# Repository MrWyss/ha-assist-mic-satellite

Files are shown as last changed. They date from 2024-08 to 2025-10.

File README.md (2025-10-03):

# Voice Assistant Mic Satellite







<p align="center">
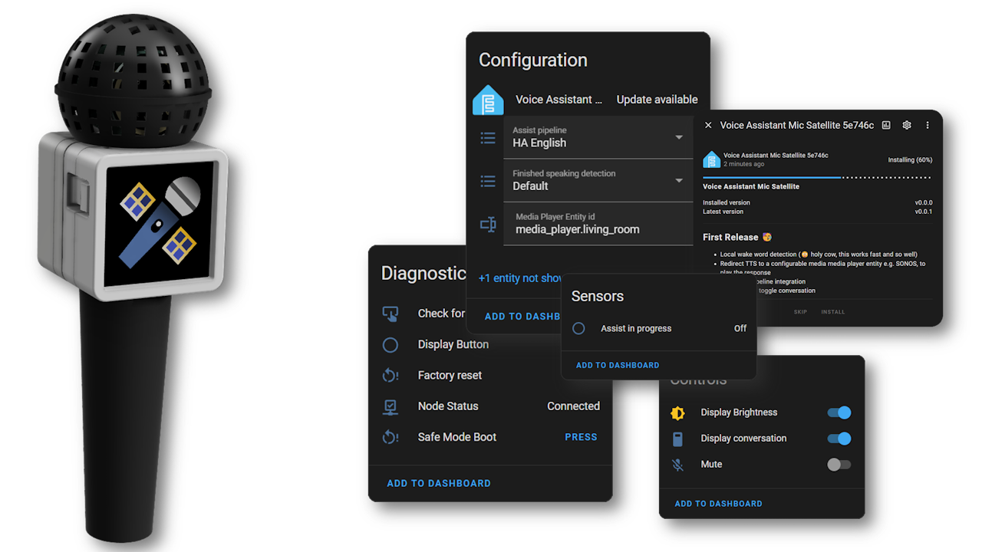
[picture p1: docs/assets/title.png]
Title Logo
  
</p>

***<p align="center" style="text-align: center;">«The VA Mic Satellite is a compact, ESPHome-based microphone solution designed to integrate with your existing sound setup..»</p>***

>📢 2025-10-03: Firmware release [v2.0.0](https://github.com/MrWyss/ha-assist-mic-satellite/releases/tag/v2.0.0) 🎉🎉🎉: **Mayor Release**, this pushes the [M5Stack AtomS3](https://docs.m5stack.com/en/core/AtomS3) to **it's limit**. With these new features 
> - Option to change from "Okey Nabu" to "Hey Jarvis" and back
> - "Set Up Voice Assistant" wizard will run on first boot
> - ESPHome 2025.9.2
>
>... [Read more](https://github.com/MrWyss/ha-assist-mic-satellite/releases)
>
>📢 2024-08-19: Version 1 released. 🎉🎉🎉 and  [PCB rev. 3](https://github.com/MrWyss/ha-assist-mic-satellite/discussions/15#discussion-7049397) has arrived and tested successfully. 🥳. See the new firmware [in action](https://github.com/MrWyss/ha-assist-mic-satellite/discussions/16#discussioncomment-10387199) on a [mic stand](https://github.com/MrWyss/ha-assist-mic-satellite/discussions/16#discussioncomment-10387101) 😆.
>
>📢 2024-08-12: I just came across the [announcement](https://www.youtube.com/watch?v=Vp5q4RIwCX4) of **Satellite1** by [Future Proof Homes](https://futureproofhomes.net). It’s an amazing initiative! 😎 My project is entirely different and not comparable to theirs. The similar name is just a coincidence. Definitely check them out!

## Features

A ~~tiny~~ Atom version of the [ESP32-S3-BOX](https://esphome.io/projects/index.html)

- Local / On Device **wake word detection** (😲 holy cow, this works fast and so well)
- Redirect TTS to a configurable **media player entity** e.g. SONOS, to play the response
- HA **Assist Pipeline integration**
- Toggle **mute**, toggle **conversation text** and control display **brightness**
- **Show current state** (listening, idle, request, response) on the display. It is fairly readable, though it requires good eyesight 👀.
- **Timers** support (plural), realistically up to 4 timers
- Easy firmware flashing via the [web installer](https://mrwyss.github.io/ha-assist-mic-satellite/)
- Managed updates

### Roadmap

If anyone is interested in contributing, here are some ideas:

- [ ] Better alarm **sound files** [#10](https://github.com/MrWyss/ha-assist-mic-satellite/issues/10)
  
## TL;DR

Gather the following items: [M5Stack AtomS3](#bom), [pcb](#pcb), [pin headers and pin sockets](#bom) and an [INMP441](#bom) breakout board.
3D print the [case](#case), [assemble](#assembly) it, [flash the firmware](#firmware), [configure](#home-assistant) the device in Home Assistant.

## Try it out / Tricks

- **Wake Word**: "Okay Nabu" (or "Hey Jarvis")
- Create a timer, *Create a 3 minute timer for Bananas*, *Cancel Bananas timer*
- The display itself is also a button, so you can **long press (~800ms) to mute** the device, it stops listening for the wake word. Holding for ~10s factory resets the device.
- If you have [Music Assistant](https://music-assistant.io) you can change the **announcement volumes**. Goto the Music Assistant Addon -> Settings -> Players -> Your Speaker -> Configure -> Announcements configuration

## Hardware

### BOM

- [M5Stack AtomS3](https://docs.m5stack.com/en/core/AtomS3) ~15$
- [PCB](#pcb) ~5$ + shipping
- [Case](#case) ~0.5$ filament
- **INMP441** breakout board (usually comes with pin sockets) ~2$
  - 2x Pin socket 1x03 2.54mm (J3, J4)
- 1x Pin header 1x05 2.54mm (J1)
- 1x Pin header 1x04 2.54mm (J2)
- M2 x 5mm screw nylon or with metal with nylon washer (optional)

### PCB

The pcb was designed in KiCAD. [KiCAD Canvas Online View](https://kicanvas.org/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) | [KiCad Project](pcb/Mic%20HAT%20for%20M5Stack%20Atom) | [PCB Step File](<pcb/Mic HAT for M5Stack Atom/Mic HAT for M5Stack Atom.step>)

Order from [PCBWay Project Link](https://www.pcbway.com/project/shareproject/HA_Assist_Mic_Satellite_f5cc4682.html) (🛒 affiliated link)

| PCB front | PCB back |
|:---:|:---:|
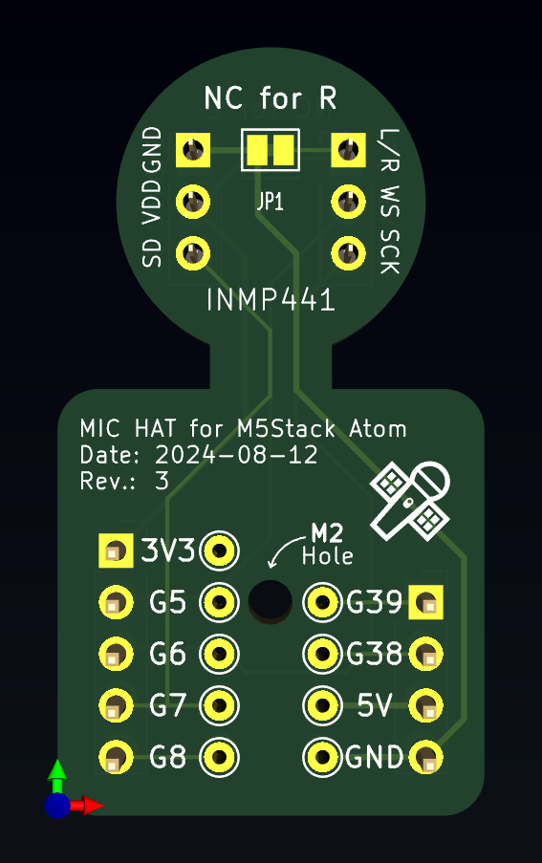
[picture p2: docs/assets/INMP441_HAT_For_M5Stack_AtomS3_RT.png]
PCB Front
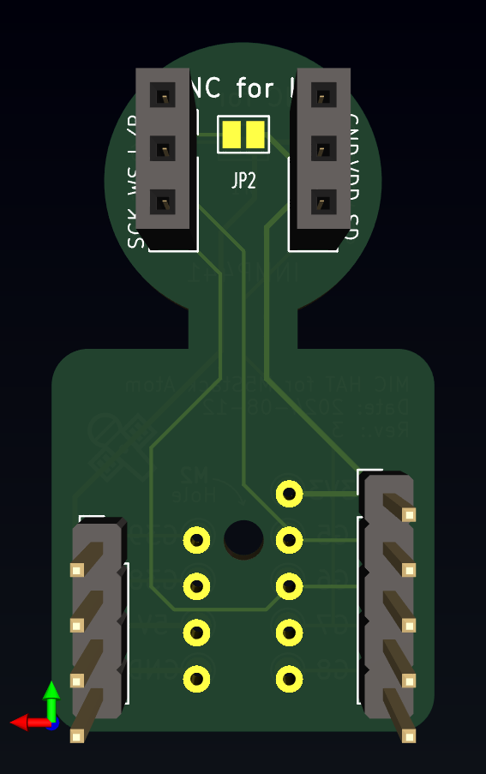
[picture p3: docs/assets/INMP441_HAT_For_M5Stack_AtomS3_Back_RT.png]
PCB Back
| | |

### Case

#### Hat

The case was designed in Fusion 360 and exported as 3mf files and step files. [Step files](case/step) | [3mf files](case/3mf)
It shouldn't need any supports for 3d printing, but I recommend printing it with your high detail settings. It is rather small.

- [Hat case body](case/3mf/MicHatCaseBody.3mf)
- [Hat case top](case/3mf/MicHatCaseTop.3mf)

#### Optional (boom, wind screen, stand)

[Boom for Grove connector](case/3mf/MicHatHolderGrove.3mf), the boom was designed for the Grove connector, as it is more centered. I sacrificed a sleeved USB cable and attached a Grove connector to it. It's supposed to be a press fit. [Mic wind screen](case/3mf/MicHatCaseWindShield.3mf), this is purely cosmetic and serves no functional purpose. [Mic stand](case/3mf/MicStandMicAll.3mf), to assemble the mic stand, you need a 8mm (~1 meter / hollow) aluminum rod. Cut into approximately three 10cm pieces, one 20cm (vertical) and one 25cm (horizontal).

### Assembly

Pretty straight forward. Solder the header sockets and pins to the pcb and to the INMP441.

>❗Check the direction of the header sockets and pins. Especially on the INMP441, the side with mic icon should face the same direction as the screen.

Put it in the case, screw it together and attach the HAT to the AtomS3.

<p align="center">
  
</p>

## Software

- [Home Assistant](https://www.home-assistant.io) (*ESPHome not required only if you want to adopt the device*)
- [Music Assistant](https://music-assistant.io) (optional)
- A **media player entity** (e.g. media_player.office)

### Firmware

The firmware is available here: [Web Installer](https://mrwyss.github.io/ha-assist-mic-satellite/) or [ESPHome yaml](code/esphome/va-mic-sat-atoms3.yaml)

This has been frankensteined together from various sources. I will try to give [credit](#credits) where [credit](#credits) is due.

### Home Assistant

The device should get auto discovered.

We need to tick **Allow the device to perform Home Assistant actions**. Since the firmware will call the `media_player.play_media` service, we need to allow this.
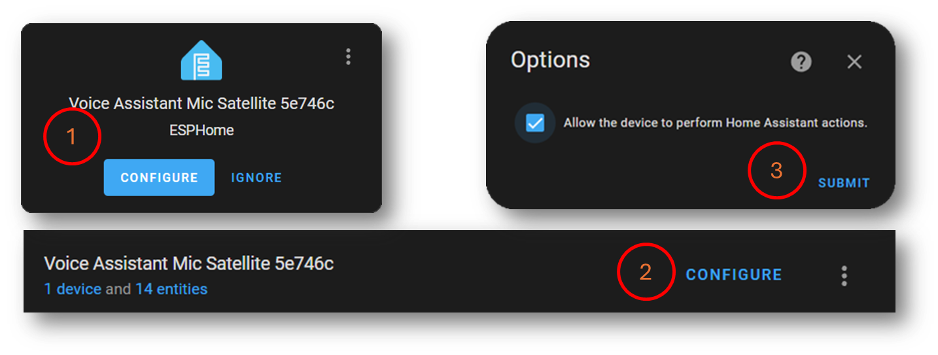
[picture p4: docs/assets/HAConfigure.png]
Configure ESPHome Device


While you here, click on **device** and change paste your media player entity id where the announcement should be played.

### Sounds

There are **two** sound files required. One for when the device is listening, this is the silent wav file, the second is for the alarm ringtone.

Currently the firmware is configured that the media player streams the files directly from github, in other words it (media_player) requires an internet connection. If you want to change this, adopt the device in ESPHome and change the following lines to something like this:

```yaml
substitutions:
  # ....
  timer_sound_file: media-source://media_source/local/my-alarm.mp3
  silence_sound_file: media-source://media_source/local/my-silence.mp3
```

To copy the sound files to for instance the home assistant, you can use the vscode addon or samba share. See more [Home Assistant Docs](https://www.home-assistant.io/integrations/media_source/)

## How it works

### Simplified Process

```mermaid
sequenceDiagram
    participant Mic Satellite
    participant Assist Pipeline
    participant media_player
    Mic Satellite->Mic Satellite: wake word detection
    Mic Satellite->>media_player: trigger action media_player.play_media (announcement / silent audio)
    media_player->media_player: lower volume
    Mic Satellite->Mic Satellite: listening  
    Mic Satellite->>Assist Pipeline: send intent audio
    Assist Pipeline->>Mic Satellite: response mp3_url
    Mic Satellite->>media_player: trigger action media_player.play_media (announcement / mp3_url)
    media_player->media_player: play response
```

### Wiring / Schematics

[KiCAD Schematic](<pcb/Mic HAT for M5Stack Atom/Mic HAT for M5Stack Atom.kicad_sch>) | [KiCAD Canvas Online View](https://kicanvas.org/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)

All the the pcb hat does is connecting the INMP441 pins to the AtomS3 pins.

<details><summary>Pin mapping table</summary>

|AtomS3 Pin|INMP441 Pin|
|:---:|:---:|
|3V3| VDD|
|GND | GND + L/R|
|G5 (GPIO5) | WS|
|G6 (GPIO6) | SCK|
|G7 (GPIO7) | SD|

</details>

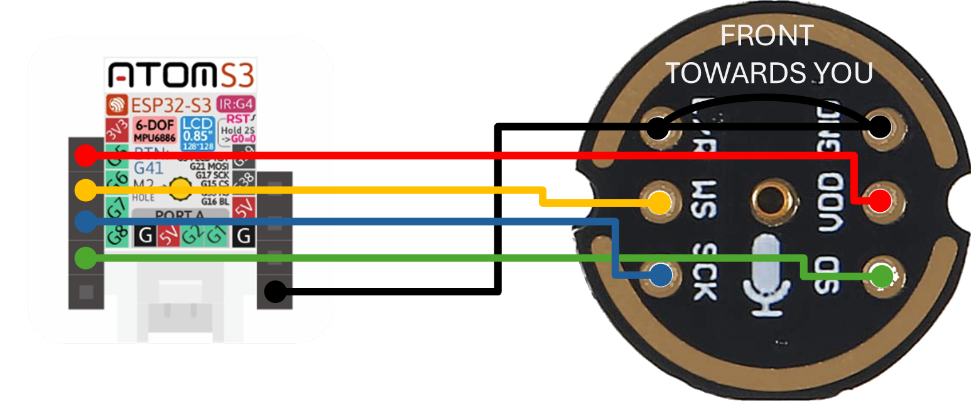
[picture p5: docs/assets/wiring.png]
wiring


Additionally, it exposes the remaining pins of the AtomS3 and adds two solder bridges (JP1 and JP2). G8, G38, and G39 are available to use for other purposes. So is the Grove connector (G1, G2). Power (+3V3 and +5V) and ground are also available.

The solder bridges are used to change the audio channel, left or right. There are two configurations:

- Left channel: JP1 bridged and JP2 not bridged (default)
- Right channel: JP1 not bridged and JP2 bridged

>❗To change the configuration, both solder bridges need to be modified. Cut one and bridge the other. I cloud otherwise short +3V3 to GND.

## Picture Gallery

<details><summary>Videos and Pictures</summary>

### Demo Video v1.0.0

https://github.com/user-attachments/assets/9a9f7f58-b787-4129-acef-4c1b4aa1fa7d

### Demo Pictures v1.0.0

Mic Stand

### Close Ups

|Close up | Full device with cable&nbsp;&nbsp;&nbsp;&nbsp;&nbsp;&nbsp;&nbsp;&nbsp;&nbsp;&nbsp;&nbsp;&nbsp;&nbsp;&nbsp;&nbsp;&nbsp;&nbsp;&nbsp;&nbsp;&nbsp;&nbsp;&nbsp;&nbsp;&nbsp;&nbsp;&nbsp;&nbsp;&nbsp;&nbsp;&nbsp;&nbsp;&nbsp;&nbsp;&nbsp;&nbsp;&nbsp;&nbsp;&nbsp;&nbsp;&nbsp;&nbsp;&nbsp;&nbsp;&nbsp;&nbsp;&nbsp;&nbsp;&nbsp;&nbsp;&nbsp;&nbsp;&nbsp;&nbsp;&nbsp;&nbsp;&nbsp;|
|:---:|:---:|
|Close Up | Full device with cable|

### Archive

|Muted |  Intent in Action|
|:---:|:---:|
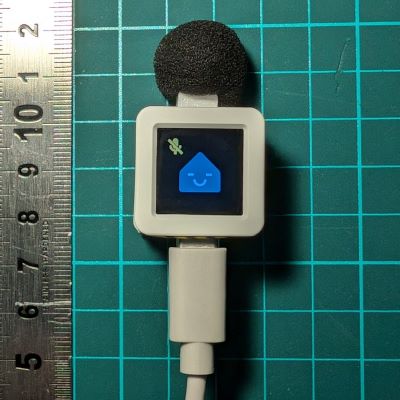
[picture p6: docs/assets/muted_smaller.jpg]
Muted
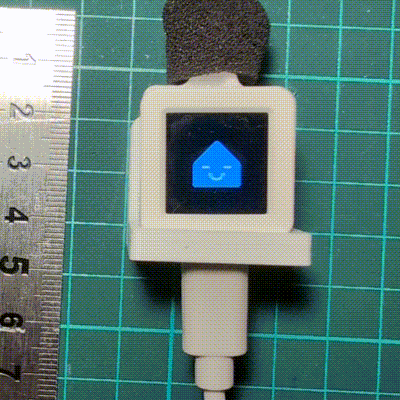
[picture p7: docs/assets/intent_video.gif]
Intent in Action
| | |

</details>

## Background

I am not an electrical engineer nor a software developer. This project is for fun and to learn new things, such as PCB design with KiCad, CAD, and ready-made ESPHome projects.

I am aware that Nabu Casa is working on a [Voice Kit](https://github.com/esphome/voice-kit); in fact, many things are directly taken from their project.
I am excited to see what the final product will look like and might even buy it myself.

My motivation was to have a small device that integrates with my existing sound setup (SONOS, in my case) rather than having a separate speaker.

## License

I wasn't sure if I should use the same license as the ESPHome project, but I think it is fine.

## Contributing

**Please do**, create issues, pull requests, open a discussion or DM me here. I am happy to help and learn from you.

## Credits

- [HA Voice Kit](https://github.com/esphome/voice-kit)
- [ESPHome Voice Assistant Github Repo](https://github.com/esphome/firmware/tree/main/voice-assistant/)
- [Smart Home Circle](https://smarthomecircle.com/How-I-created-my-voice-assistant-with-on-device-wake-word-using-home-assistant)
- [Community](https://community.home-assistant.io/t/esphome-voice-assistant-speech-output-to-home-assistant-media-player/588337/18)
- And obviously the Nabu Casa team

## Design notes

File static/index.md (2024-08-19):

# About

The Voice Assistant Mic Satellite is a compact, ESPHome-based microphone solution designed for seamless integration with Home Assistant.

# Installation

You can use the button below to install the pre-built firmware directly to your device via USB from the browser.

<esp-web-install-button manifest="./firmware/manifest.json"></esp-web-install-button>

<script type="module" src="https://unpkg.com/esp-web-tools@9/dist/web/install-button.js?module"></script>

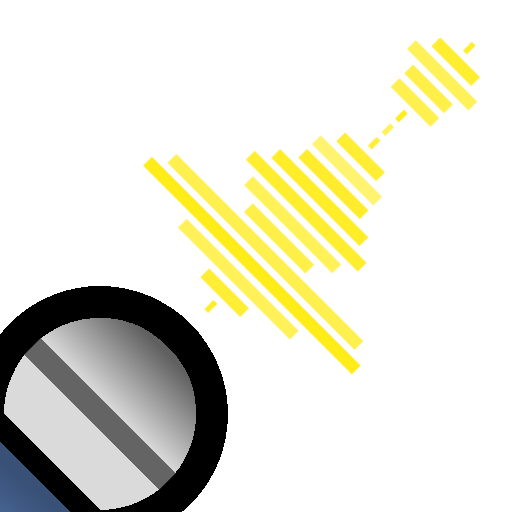
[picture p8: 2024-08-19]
code/esphome/media/animation/micsatellite_listening.png

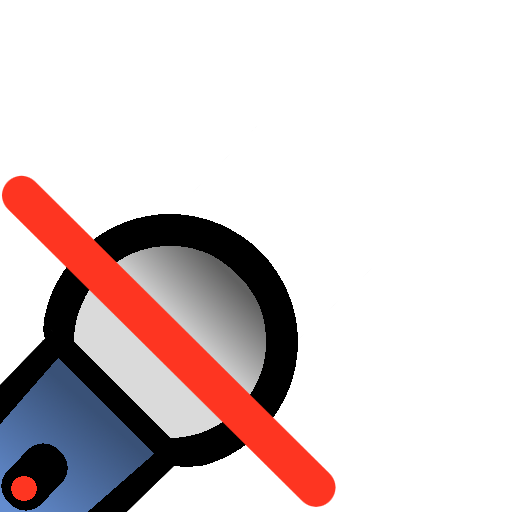
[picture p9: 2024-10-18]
code/esphome/media/animation/micsatellite_idle_mute.png

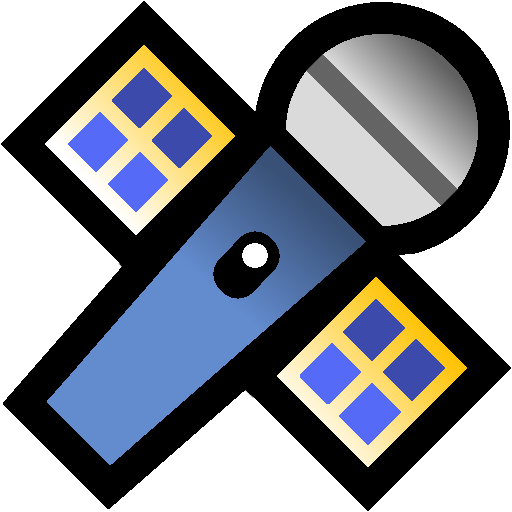
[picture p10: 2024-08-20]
code/esphome/media/animation/MicSatellite.png

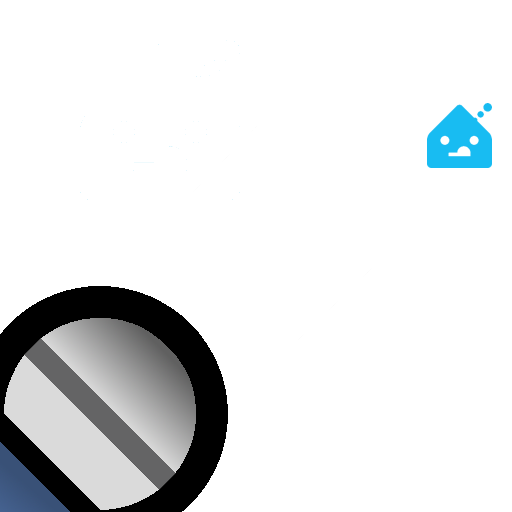
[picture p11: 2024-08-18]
code/esphome/media/animation/micsatellite_thinking.png

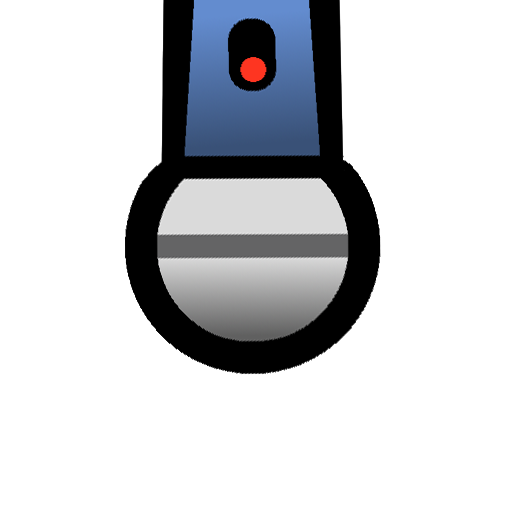
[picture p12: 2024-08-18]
code/esphome/media/animation/micsatellite_error.png

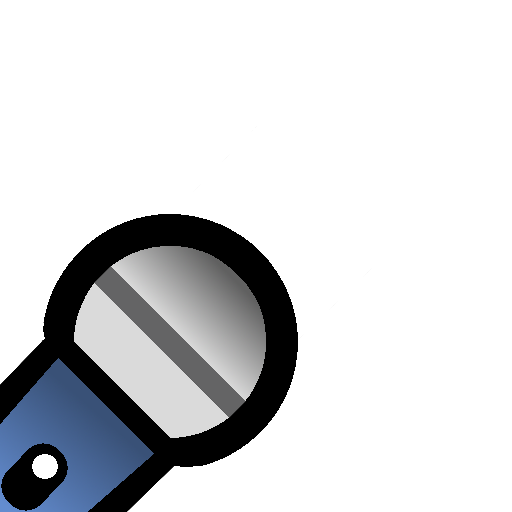
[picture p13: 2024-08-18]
code/esphome/media/animation/micsatellite_idle.png

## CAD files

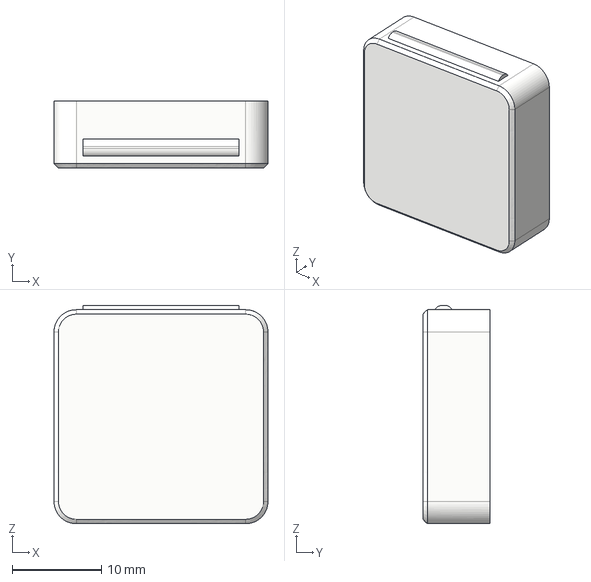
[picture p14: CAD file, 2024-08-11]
case/step/Mic Hat Case Top.step
24.0 x 7.51 x 24.5 mm

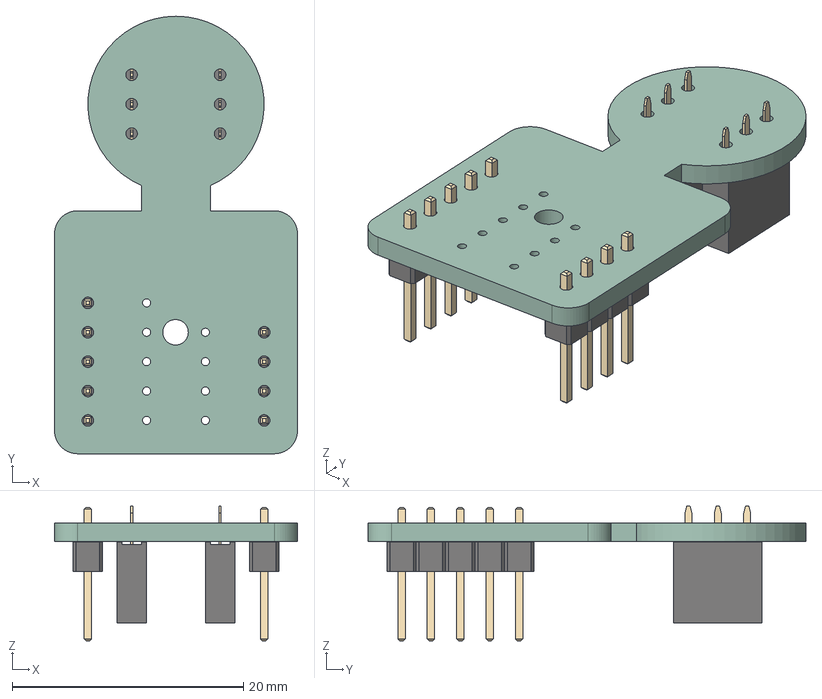
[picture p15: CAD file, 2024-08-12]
pcb/Mic HAT for M5Stack Atom/Mic HAT for M5Stack Atom.step
21.0 x 37.8 x 11.6 mm
PinHeader_1x05_P254mm_Vertical
PinHeader_1x04_P254mm_Vertical
PinSocket_1x03_P254mm_Vertical x 2
Mic HAT for M5Stack Atom_PCB

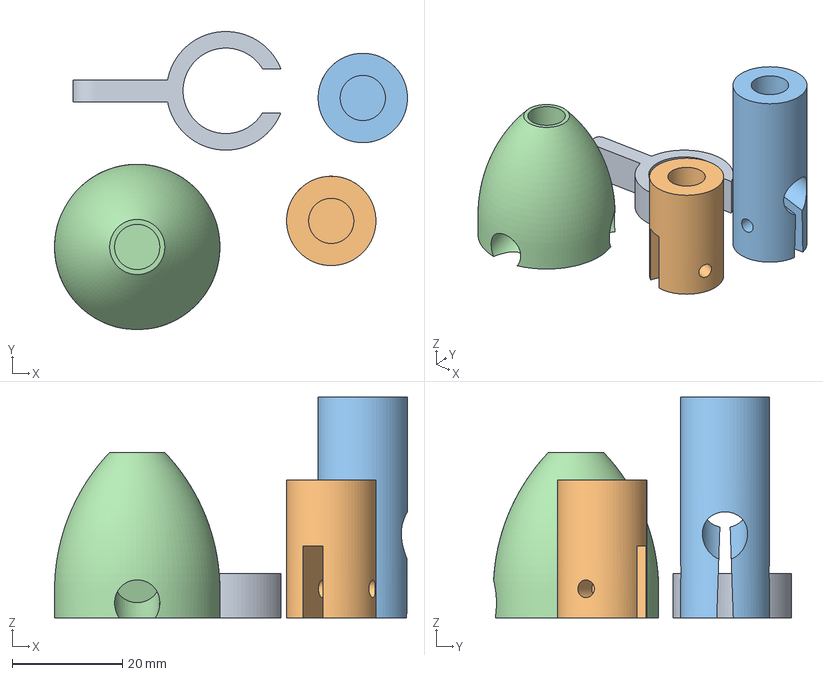
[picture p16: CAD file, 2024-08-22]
case/3mf/MicStandMicAllStructureParts.3mf
64.0 x 54.0 x 40.0 mm
MicStandMicHolder
MicStandLastJunction
MicStandJunction
MicStandBottom

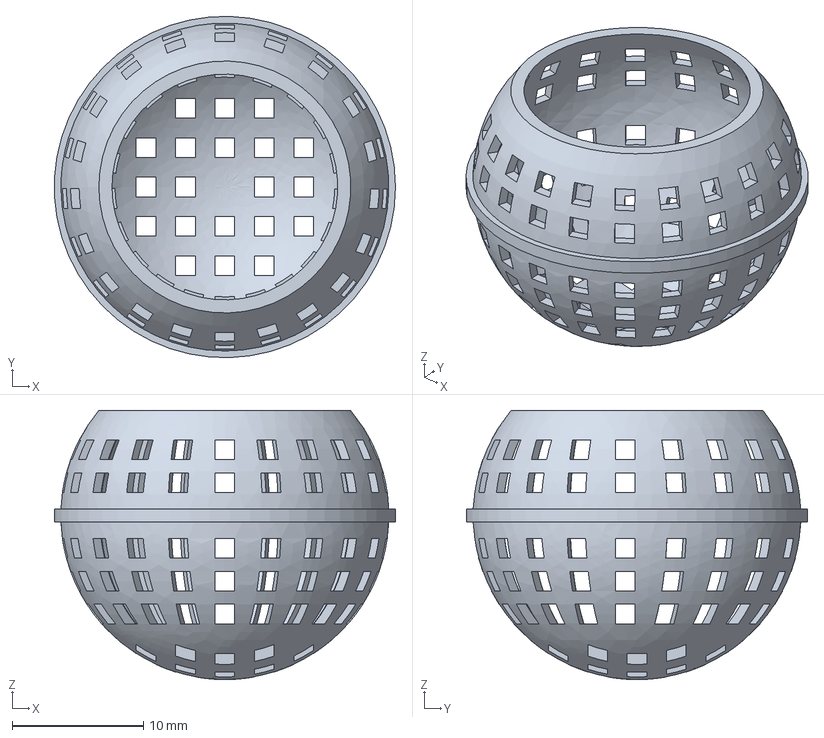
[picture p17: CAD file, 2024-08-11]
case/step/Mic Hat Case Wind Shield.step
26.0 x 26.0 x 20.5 mm

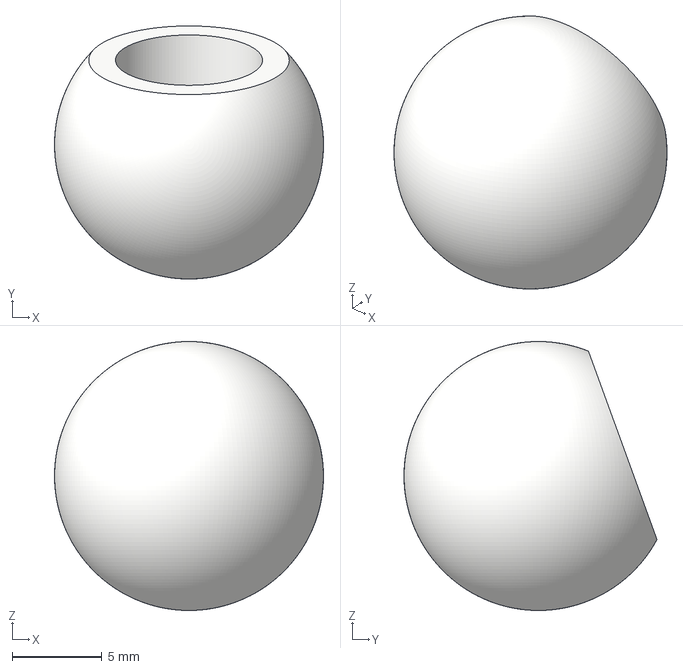
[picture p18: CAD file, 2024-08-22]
case/3mf/MicStandFeets.3mf
15.0 x 14.1 x 15.0 mm

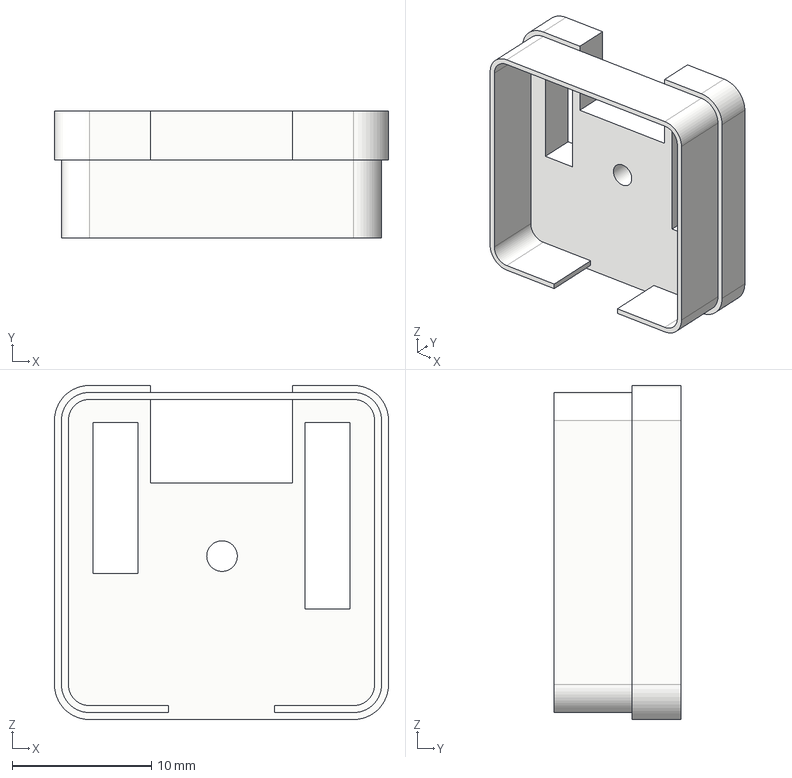
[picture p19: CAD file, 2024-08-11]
case/step/Mic Hat Case Body.step
24.0 x 9.11 x 24.0 mm

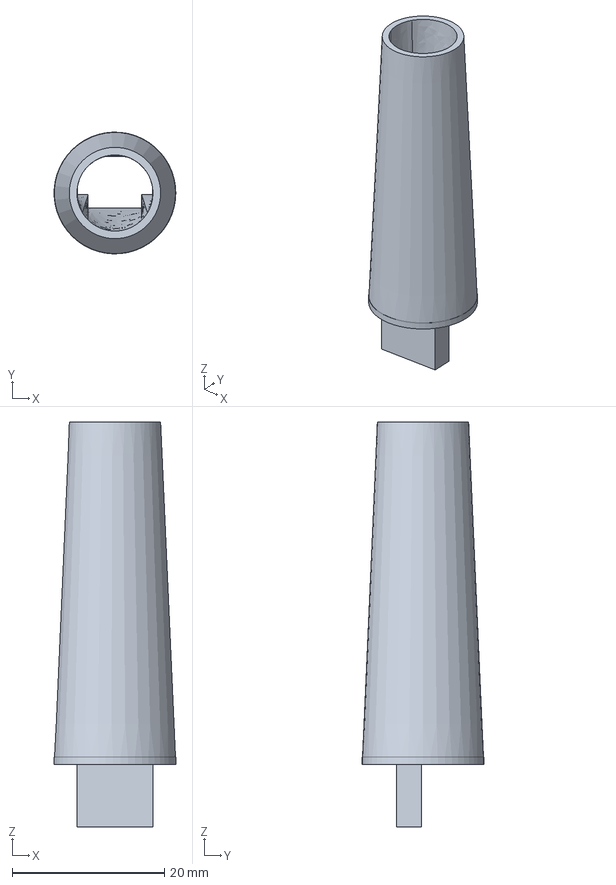
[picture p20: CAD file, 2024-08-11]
case/step/Mic Hat Holder Grove.step
16.0 x 16.0 x 53.2 mm

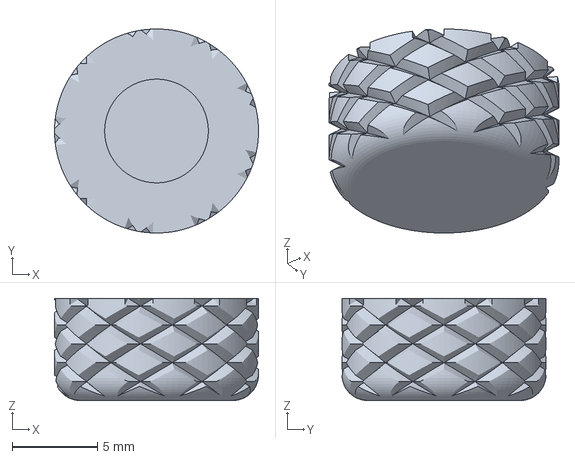
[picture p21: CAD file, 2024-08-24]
case/3mf/MicStandThumbscrew_KnurledCap.3mf
12.0 x 12.0 x 6.00 mm

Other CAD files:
case/3mf/MicHatCaseBody.3mf
case/3mf/MicHatCaseTop.3mf
case/3mf/MicHatCaseWindShield.3mf
case/3mf/MicHatHolderGrove.3mf

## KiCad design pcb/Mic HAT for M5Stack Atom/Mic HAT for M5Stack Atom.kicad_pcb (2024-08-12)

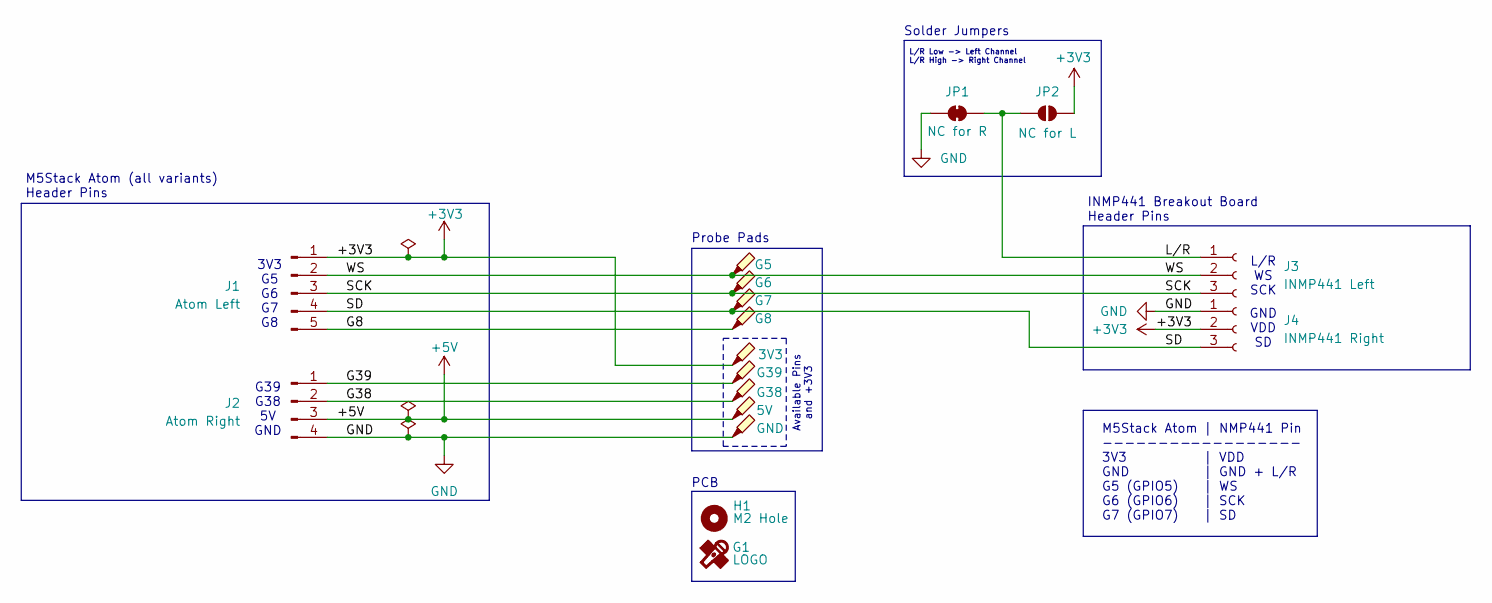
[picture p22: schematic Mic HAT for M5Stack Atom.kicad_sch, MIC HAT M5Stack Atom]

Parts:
3V3: 3V3; TestPoint_THTPad_D1.5mm_Drill0.7mm
5V1: 5V; TestPoint_THTPad_D1.5mm_Drill0.7mm
G1: LOGO; Logo
G5: G5; TestPoint_THTPad_D1.5mm_Drill0.7mm
G6: G6; TestPoint_THTPad_D1.5mm_Drill0.7mm
G7: G7; TestPoint_THTPad_D1.5mm_Drill0.7mm
G8: G8; TestPoint_THTPad_D1.5mm_Drill0.7mm
G38: G38; TestPoint_THTPad_D1.5mm_Drill0.7mm
G39: G39; TestPoint_THTPad_D1.5mm_Drill0.7mm
GND1: GND; TestPoint_THTPad_D1.5mm_Drill0.7mm
H1: M2 Hole; M2Hole
J1: Atom Left; PinHeader_1x05_P2.54mm_Vertical
J2: Atom Right; PinHeader_1x04_P2.54mm_Vertical
J3: INMP441 Left; PinSocket_1x03_P2.54mm_Vertical
J4: INMP441 Right; PinSocket_1x03_P2.54mm_Vertical
JP1: NC for R; SolderJumper-2_P1.3mm_Bridged_Pad1.0x1.5mm
JP2: NC for L; SolderJumper-2_P1.3mm_Open_Pad1.0x1.5mm

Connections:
+3V3: 3V3.1, J1.1, J4.2, JP2.1 (A)
+5V: 5V1.1, J2.3
/G8: G8.1, J1.5
/G38: G38.1, J2.2
/G39: G39.1, J2.1
/L/R: J3.1, JP1.1 (A), JP2.2 (B)
/SCK: G6.1, J1.3, J3.3
/SD: G7.1, J1.4, J4.3
/WS: G5.1, J1.2, J3.2
GND: GND1.1, J2.4, J4.1, JP1.2 (B)

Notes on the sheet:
3V3 G5 G6 G7 G8
M5Stack Atom (all variants) Header Pins
L/R WS SCK
Available Pins and +3V3
Solder Jumpers
M5Stack Atom -------- 3V3 GND G5 (GPIO5) G6 (GPIO6) G7 (GPIO7)
Probe Pads
PCB
| NMP441 Pin ---------- | VDD | GND + L/R | WS | SCK | SD
INMP441 Breakout Board Header Pins
GND VDD SD
G39 G38 5V GND
L/R Low -> Left Channel L/R High -> Right Channel

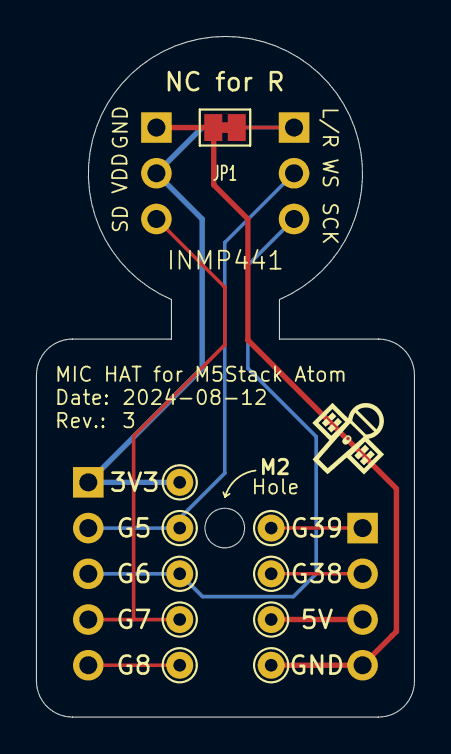
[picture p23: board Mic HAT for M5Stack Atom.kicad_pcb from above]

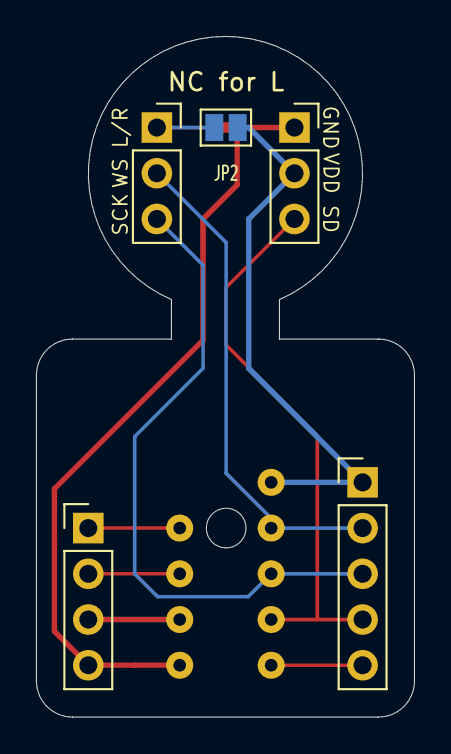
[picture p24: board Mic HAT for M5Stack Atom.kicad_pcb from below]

Board: 2 copper layers, 21.0 x 37.8 mm, 17 parts (5 on the bottom side), 10 nets.

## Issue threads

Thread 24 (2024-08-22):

Resolve issue where mute setting is not retained upon device reconnection to Home Assistant

MrWyss, 2024-08-22:
there is no check when device reconnects if it's in a mute state
```yaml
api:
  on_client_connected:
    then:
      - delay: 10s
      - micro_wake_word.start
```

Closed 2024-08-24.

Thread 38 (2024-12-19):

Shorten Device Friendly Name

MrWyss, 2024-12-19:
Change `Voice Assistant Mic Satellite` to `Mic Satellite`. That is a much cleaner when adding entities to the dashboard and in other areas of HA.

Closed 2024-12-19.

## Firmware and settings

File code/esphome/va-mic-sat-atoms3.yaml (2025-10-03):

substitutions:
  version: "v2.0.0"
  
  # Optional
  timer_sound_file: https://github.com/esphome/home-assistant-voice-pe/raw/dev/sounds/timer_finished.flac
  #silence_sound_file: https://github.com/MrWyss/ha-assist-mic-satellite/raw/main/code/esphome/media/sounds/5s_silent.wav
  #timer_sound_file: media-source://media_source/local/timer_finished.mp3
  #silence_sound_file: media-source://media_source/local/10-seconds-of-silence.mp3
  
  voice_assist_idle_phase_id: "1"
  voice_assist_listening_phase_id: "2"
  voice_assist_thinking_phase_id: "3"
  voice_assist_replying_phase_id: "4"
  voice_assist_not_ready_phase_id: "10"
  voice_assist_error_phase_id: "11"
  voice_assist_timer_finished_phase_id: "13"
  voice_assist_credits_phase_id: "42"
  voice_assist_status_phase_id: "99"

 
esphome:
  name: va-mic-sat-atoms3
  friendly_name: Mic Satellite
  name_add_mac_suffix: true
  platformio_options:
    board_build.flash_mode: dio
    board_build.variant: m5stack-atoms3
  project: 
    name: MrWyss.Mic Satellite
    version: ${version}
  on_boot:
    priority: 600
    then:
      - script.execute: draw_display

esp32:
  board: esp32-s3-devkitc-1
  variant: esp32s3
  flash_size: 8MB
  framework:
    type: esp-idf
    sdkconfig_options:
      CONFIG_ESP32S3_DEFAULT_CPU_FREQ_240: "y"
      #CONFIG_SPIRAM_ALLOW_STACK_EXTERNAL_MEMORY: "y"
      #CONFIG_ESP32S3_DATA_CACHE_64KB: "y"
      #CONFIG_ESP32S3_DATA_CACHE_LINE_64B: "y"
      #CONFIG_ESP32_S3_BOX_BOARD: "y"

wifi:
  ap: {}
  on_connect:
    - script.execute: draw_display
  on_disconnect:
    - script.execute: draw_display

# Enable logging
logger:
  level: DEBUG

# Enable Home Assistant API
api:
  on_client_connected: 
    then:
      - if:
          condition:
            lambda: return id(init_in_progress);
          then:
            - lambda: id(init_in_progress) = false;
            - script.execute: draw_display

ota:
  - platform: esphome
    id: ota_esphome
  - platform: http_request
    id: ota_http_request

http_request:
  buffer_size_rx : 1024
  buffer_size_tx : 1024


update:
  - platform: http_request
    name: None
    id: update_http_request
    source: https://mrwyss.github.io/ha-assist-mic-satellite/firmware/manifest.json

captive_portal:

dashboard_import:
  package_import_url: github://MrWyss/ha-assist-mic-satellite/code/esphome/va-mic-sat-atoms3.yaml@main                   
  import_full_config: true

improv_serial:

# Disable in favor of memory
#esp32_improv:
#  authorizer: none

web_server:

globals:
  - id: contributors
    type: std::vector<std::string>
    initial_value: |-
      {
        "Nabu Casa &", 
        "Home Assistant",
        "HA Community", 
        "***********", 
        "Your Name could be", 
        "burned in to", 
        "Firmware here", 
      }
  
  - id: init_in_progress
    type: bool
    restore_value: false
    initial_value: "true"

  - id: voice_assistant_phase
    type: int
    restore_value: false
    initial_value: ${voice_assist_not_ready_phase_id}
 
  - id: timers_text
    type: std::string
    restore_value: false
    initial_value: ""

  - id: lines_array
    type: std::vector<std::string>

  - id: line_spacing
    type: int
    restore_value: false
    initial_value: '12'

  - id: max_line_length
    type: int
    restore_value: false
    initial_value: '20'
  
  - id: max_line_count
    type: int
    restore_value: false
    initial_value: '4'

  - id: display_duration
    type: int
    restore_value: false
    initial_value: '8000'

button:
  - platform: safe_mode
    id: button_safe_mode
    name: Safe Mode Boot
    entity_category: diagnostic

  - platform: factory_reset
    id: factory_reset_btn
    name: Factory reset
    entity_category: diagnostic
    
  # TODO: Remove before launch, added for testing/development
  - platform: template
    name: Check for update
    entity_category: diagnostic
    on_press:
      - component.update: update_http_request
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

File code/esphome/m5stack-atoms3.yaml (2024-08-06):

#TODO:
# - Timer Page
# - Timer Tests / Update with voice and cancle with voice
# - silence sound file location
# - 


substitutions:
  loading_illustration_file: https://github.com/esphome/firmware/raw/main/voice-assistant/casita/loading_320_240.png
  idle_illustration_file: https://github.com/esphome/firmware/raw/main/voice-assistant/casita/idle_320_240.png
  listening_illustration_file: https://github.com/esphome/firmware/raw/main/voice-assistant/casita/listening_320_240.png
  thinking_illustration_file: https://github.com/esphome/firmware/raw/main/voice-assistant/casita/thinking_320_240.png
  replying_illustration_file: https://github.com/esphome/firmware/raw/main/voice-assistant/casita/replying_320_240.png
  error_illustration_file: https://github.com/esphome/firmware/raw/main/voice-assistant/casita/error_320_240.png
  timer_sound_file: https://github.com/esphome/firmware/raw/main/voice-assistant/sounds/timer_finished.wav
  silence_sound_file: media-source://media_source/local/10-seconds-of-silence.mp3
  loading_illustration_background_color: "000000"
  idle_illustration_background_color: "000000"
  listening_illustration_background_color: "FFFFFF"
  thinking_illustration_background_color: "FFFFFF"
  replying_illustration_background_color: "FFFFFF"
  error_illustration_background_color: "000000"
  mute_on_circle_color: "F7931E"
  #mute_off_circle_color: "41B3EF"

  voice_assist_idle_phase_id: "1"
  voice_assist_listening_phase_id: "2"
  voice_assist_thinking_phase_id: "3"
  voice_assist_replying_phase_id: "4"
  voice_assist_not_ready_phase_id: "10"
  voice_assist_error_phase_id: "11"
  voice_assist_muted_phase_id: "12"
  voice_assist_timer_finished_phase_id: "13"

  allowed_characters: " !#%'()+,-./0123456789:;<>?@ABCDEFGHIJKLMNOPQRSTUVWYZ[]_abcdefghijklmnopqrstuvwxyz{|}°²³µ¿ÁÂÄÅÉÖÚßàáâãäåæçèéêëìíîðñòóôõöøùúûüýþāăąćčďĐđēėęěğĮįıļľŁłńňőřśšťũūůűųźŻżŽžơưșțΆΈΌΐΑΒΓΔΕΖΗΘΚΜΝΠΡΣΤΥΦάέήίαβγδεζηθικλμνξοπρςστυφχψωϊόύώАБВГДЕЖЗИКЛМНОПРСТУХЦЧШЪЭЮЯабвгдежзийклмнопрстуфхцчшщъыьэюяёђєіїјљњћאבגדהוזחטיכלםמןנסעפץצקרשת،ءآأإئابةتجحخدذرزسشصضطظعغفقكلمنهوىيٹپچڈکگںھہیےংকচতধনফবযরলশষস়ািু্చయలిెొ్ംഅആഇഈഉഎഓകഗങചജഞടഡണതദധനപഫബഭമയരറലളവശസഹാിീുൂെേൈ്ൺൻർൽൾაბგდევზთილმნოპრსტუფქყშჩცძჭხạảấầẩậắặẹẽếềểệỉịọỏốồổỗộớờởợụủứừửữựỳ—、一上不个中为主乾了些亮人任低佔何作供依侧係個側偵充光入全关冇冷几切到制前動區卧厅厨及口另右吊后吗启吸呀咗哪唔問啟嗎嘅嘛器圍在场執場外多大始安定客室家密寵对將小少左已帘常幫幾库度庫廊廚廳开式後恆感態成我戲戶户房所扇手打执把拔换掉控插摄整斯新明是景暗更最會有未本模機檯櫃欄次正氏水沒没洗活派温測源溫漏潮激濕灯為無煙照熱燈燥物狀玄现現瓦用發的盞目着睡私空窗立笛管節簾籬紅線红罐置聚聲脚腦腳臥色节著行衣解設調請謝警设调走路車车运連遊運過道邊部都量鎖锁門閂閉開關门闭除隱離電震霧面音頂題顏颜風风食餅餵가간감갔강개거게겨결경고공과관그금급기길깥꺼껐꼽나난내네놀누는능니다닫담대더데도동됐되된됨둡드든등디때떤뜨라래러렇렌려로료른를리림링마많명몇모무문물뭐바밝방배변보부불블빨뽑사산상색서설성세센션소쇼수스습시신실싱아안않알았애야어얼업없었에여연열옆오온완외왼요운움워원위으은을음의이인일임입있작잠장재전절정제져조족종주줄중줘지직진짐쪽차창천최추출충치침커컴켜켰쿠크키탁탄태탬터텔통트튼티파팬퍼폰표퓨플핑한함해했행혀현화활후휴힘，？"

globals:
  - id: init_in_progress
    type: bool
    restore_value: false
    initial_value: "true"

  - id: voice_assistant_phase
    type: int
    restore_value: false
    initial_value: ${voice_assist_not_ready_phase_id}


esphome:
  name: m5stack-atoms3
  friendly_name: M5Stack AtomS3
  name_add_mac_suffix: true
  on_boot:
    priority: 600
    then:
      - script.execute: draw_display
      - micro_wake_word.start
      - delay: 30s
      - if:
          condition:
            lambda: return id(init_in_progress);
          then:
            - lambda: id(init_in_progress) = false;
            - script.execute: draw_display

esp32:
  board: esp32-s3-devkitc-1
  framework:
    type: esp-idf #arduino

# Enable logging
logger:
  level: DEBUG
  logs:
    component: ERROR

# Enable Home Assistant API
api:
  encryption:
    key: YOURAPIKEY

ota:
  - platform: esphome
    password: YOUROTAPASSWORD

#esp32_ble:

wifi:
  ssid: !secret wifi_ssid
  password: !secret wifi_password
  # Enable fallback hotspot (captive portal) in case wifi connection fails
  ap:
    ssid: "M5Stack-AtomS3 Fallback Hotspot"
    password: YOURAPPPASSWORD
  on_connect:
    - script.execute: draw_display
    #- delay: 5s  # Gives time for improv results to be transmitted
    #- ble.disable:
  on_disconnect:
    - script.execute: draw_display
    #- ble.enable:

captive_portal:

button:
  - platform: safe_mode
    id: button_safe_mode
    name: Safe Mode Boot
    entity_category: diagnostic

  - platform: factory_reset
    id: factory_reset_btn
    name: Factory reset
    entity_category: diagnostic

#G4=IR
#remote_transmitter:
#  pin: GPIO4
#  carrier_duty_percent: 50%
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

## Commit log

2024-08-06 fix broken pcbway link
2024-08-06 3d case files and assembly instructions
    [MicHatCase v12.step, MicHatCase.3mf, MicHatCaseWindShield.3mf]
2024-08-08 online sound file and fix adopt url
    [va-mic-sat-atoms3.yaml]
2024-08-08 adding diag buttons to check for updates
2024-08-09 pcb step file
    [Mic HAT for M5Stack Atom.step]
2024-08-09 stl test
2024-08-09 STL Previews
2024-08-09 fix case text
2024-08-09 fix stl preview
2024-08-09 remove stl for pcb
2024-08-09 revert back, remove stl viewer seems to break the md
2024-08-10 Allow control of the display brightness Fixes #3
    [va-mic-sat-atoms3.yaml]
2024-08-10 human readable timer output and handling multiple timers
2024-08-10 basic timer display
2024-08-11 explain solder bridges and available pins
2024-08-11 Updates step files and adding grove handle
    [Mic Hat Case Body.step, Mic Hat Case Top.step, Mic Hat Case Wind Shield.step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]
2024-08-11 disable esp32_improv and therefore bluetooth
2024-08-11 timer tricks
2024-08-12 rev. 3, fixed big oopsy reversed headers, aligned hole and some silkscreen alignments
    [Mic HAT for M5Stack Atom.kicad_pcb]
2024-08-12 update pcb pictures and step files for rev 3
    [Mic HAT for M5Stack Atom.step]
2024-08-12 Updated Case for rev 3
    [MicHatCase.3mf, MicHatCaseBody.3mf, MicHatCaseTop.3mf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]
2024-08-13 better fit for the holder
    [MicHatHolderGrove.3mf]
2024-08-15 V0.0.2 (#21)
    * Display: Flickering slightly improved
    Fixes #17
    * Button: Improved click timing, hold is now mute, double and triple click available for other uses
    Fixes #19
    * Alarm: keeps the playing media on low volume when alarm is playing
    Fixes #10
    [va-mic-sat-atoms3.yaml]
2024-08-19 Announcement v1.0.0 and demo pics and video
    [MicStandMicAll.3mf]
2024-08-19 Redesign animations and text to optimize for the small screen (#22) (#23)
    * Redesign animations and text to optimize for the small screen (#22)
    * Redesign animations and text to optimize for the small screen
    Fixes #9
    * New screens with better readability
    [va-mic-sat-atoms3.yaml]
2024-08-19 fixes ota update via gh-pages
    [va-mic-sat-atoms3.yaml]
2024-08-19 added discussion links for the pcb and demo
2024-08-21 fix 31 character truncation, display time 8 sec as global var
    [va-mic-sat-atoms3.yaml]
2024-08-21 refactor switch statement
2024-08-22 added feets for the micstand
    [MicStandFeets.3mf]
2024-08-22 Resolve issue where mute setting is not retained upon device reconnection to Home Assistant Fixes #24
    [va-mic-sat-atoms3.yaml]
2024-08-22 Updated middle section of the mic stand
    [MicStandMicAll.3mf]
2024-08-24 Release announcement and additional 3d print files for the mic stand
    [MicStandMicAllStructureParts.3mf, MicStandThumbscrew_KnurledCap.3mf]
2024-08-25 replaced repeat with wait_until
    [va-mic-sat-atoms3.yaml]
2024-08-25 Fix wake word restart when voice assist response ended Fixes #30
    [va-mic-sat-atoms3.yaml]
2024-10-27 An announcement is already in progress.... Fixes #35
    [va-mic-sat-atoms3.yaml]
2024-11-21 Fix Font glyphsets for ESPHome version 2024.11 Fixes #37
    [va-mic-sat-atoms3.yaml]
2024-12-19 Shorten Device Friendly Name Fixes #38
    [va-mic-sat-atoms3.yaml]
2024-12-22 Polish project name and device name Fixes #41
    [va-mic-sat-atoms3.yaml]
2024-12-22 Adopt voice assistant sounds Fixes #42
    [va-mic-sat-atoms3.yaml]
2025-10-03 Fixes #46 and #7
    [va-mic-sat-atoms3.yaml]
